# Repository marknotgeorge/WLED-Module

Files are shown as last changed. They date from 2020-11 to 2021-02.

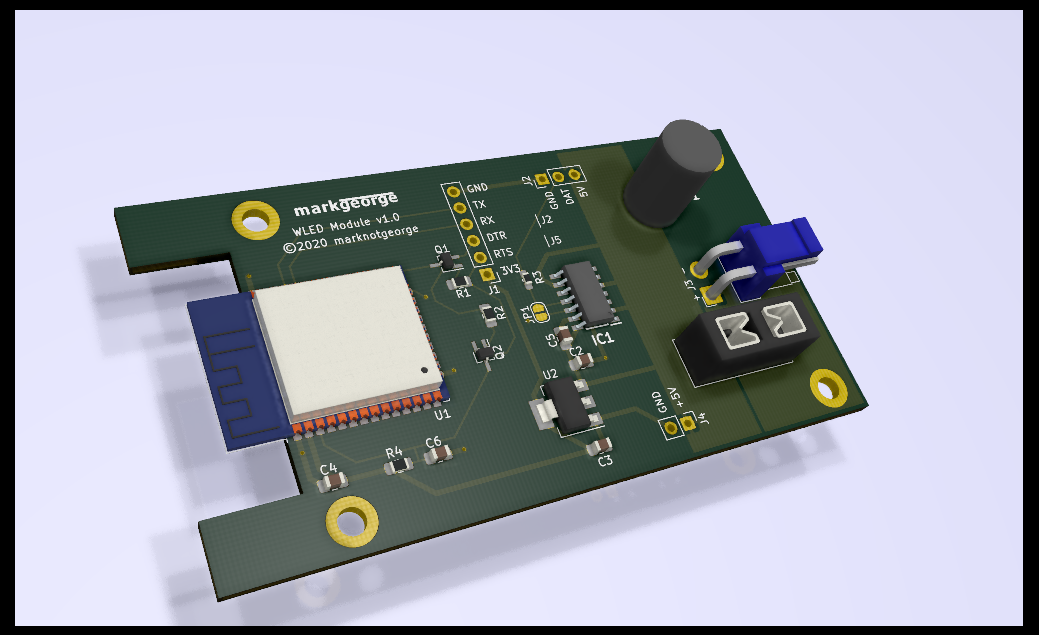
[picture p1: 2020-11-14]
WLED Module.png

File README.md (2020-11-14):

# WLED-Module
A minimal ESP32-based module for controlling a strip of WS2812 (Neopixel) LEDs using WLED

## Features
- Just the components needed. Nothing more, nothing less.
- Programming header for use with a USB-UART dongle, with auto-reset circuitry for buttonless programming.
- Powered from a 5V power brick.

## To Do
- Add extra connector block to help power long strips.
- Add strapping resistor to EN pin.
- Add JLCPCB component codes to facilitate assembly.
- Layout PCB.
- Build it!

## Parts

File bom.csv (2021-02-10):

Comment | Designator | Footprint | LCSC
EEU-FR0J102 | C1 | SamacSys:CAPPRD350W65D800H1300
22uF | C2 | Capacitor_SMD:C_0805_2012Metric_Pad1.15x1.40mm_HandSolder | C45783
22uf | C3 | Capacitor_SMD:C_0805_2012Metric_Pad1.15x1.40mm_HandSolder | C45783
0.1uF | C4,C5 | Capacitor_SMD:C_0805_2012Metric_Pad1.15x1.40mm_HandSolder | C49678
0.1uF 50V | C6 | Capacitor_SMD:C_0805_2012Metric_Pad1.15x1.40mm_HandSolder | C49678
10A | F1 | Fuse:Fuseholder_Blade_Mini_Keystone_3568
MountingHole_Pad | H1,H2,H3,H4 | MountingHole:MountingHole_3.2mm_M3_DIN965_Pad
SN74AHCT125D | IC1 | SamacSys:SOIC127P600X175-14N | C155176
Conn_02x03_Odd_Even | J1 | Connector_IDC:IDC-Header_2x03_P2.54mm_Vertical
JST SM Connector | J2 | Connector_PinHeader_2.54mm:PinHeader_1x03_P2.54mm_Vertical
Conn_01x02_Male | J3 | Connector_JST:JST_VH_B2PS-VH_1x02_P3.96mm_Horizontal
Conn_01x02_Male | J4 | Connector_PinHeader_2.54mm:PinHeader_1x02_P2.54mm_Vertical
SolderJumper_2_Open | JP1 | Jumper:SolderJumper-2_P1.3mm_Open_RoundedPad1.0x1.5mm
470R | R3 | Resistor_SMD:R_0603_1608Metric_Pad1.05x0.95mm_HandSolder | C17710
10K | R4 | Resistor_SMD:R_0805_2012Metric_Pad1.15x1.40mm_HandSolder | C17414
ESP32-WROOM-32D | U1 | RF_Module:ESP32-WROOM-32 | C473012
AMS1117-3.3 | U2 | Package_TO_SOT_SMD:SOT-223-3_TabPin2 | C6186

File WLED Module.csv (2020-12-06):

Id | Designator | Package | Quantity | Designation | Supplier and ref
1 | G*** | marknotgeorge logo | 1 | LOGO
2 | H4,H3,H2,H1 | MountingHole_3.2mm_M3_DIN965_Pad | 4 | MountingHole_Pad
3 | J3 | JST_VH_B2PS-VH_1x02_P3.96mm_Horizontal | 1 | Conn_01x02_Male
4 | F1 | Fuseholder_Blade_Mini_Keystone_3568 | 1 | 10A
5 | J2 | PinHeader_1x03_P2.54mm_Vertical | 1 | JST SM Connector
6 | R1,R2 | R_0805_2012Metric_Pad1.15x1.40mm_HandSolder | 2 | 10k
7 | Q1,Q2 | SOT-323_SC-70_Handsoldering | 2 | SS8050
8 | IC1 | SOIC127P600X175-14N | 1 | SN74AHCT125D
9 | C5,C4 | C_0805_2012Metric_Pad1.15x1.40mm_HandSolder | 2 | 0.1uF
10 | C1 | CAPPRD350W65D800H1300 | 1 | EEU-FR0J102
11 | C2 | C_0805_2012Metric_Pad1.15x1.40mm_HandSolder | 1 | 22uF
12 | C3 | C_0805_2012Metric_Pad1.15x1.40mm_HandSolder | 1 | 22uf
13 | C6 | C_0805_2012Metric_Pad1.15x1.40mm_HandSolder | 1 | 0.1uF 50V
14 | J1 | PinHeader_1x06_P2.54mm_Vertical | 1 | Conn_01x06_Male
15 | JP1 | SolderJumper-2_P1.3mm_Open_RoundedPad1.0x1.5mm | 1 | SolderJumper_2_Open
16 | R3 | R_0603_1608Metric_Pad1.05x0.95mm_HandSolder | 1 | 470R
17 | R4 | R_0805_2012Metric_Pad1.15x1.40mm_HandSolder | 1 | 10K
18 | U1 | ESP32-WROOM-32 | 1 | ESP32-WROOM-32D
19 | U2 | SOT-223-3_TabPin2 | 1 | AMS1117-3.3
20 | J4 | PinHeader_1x02_P2.54mm_Vertical | 1 | Conn_01x02_Male

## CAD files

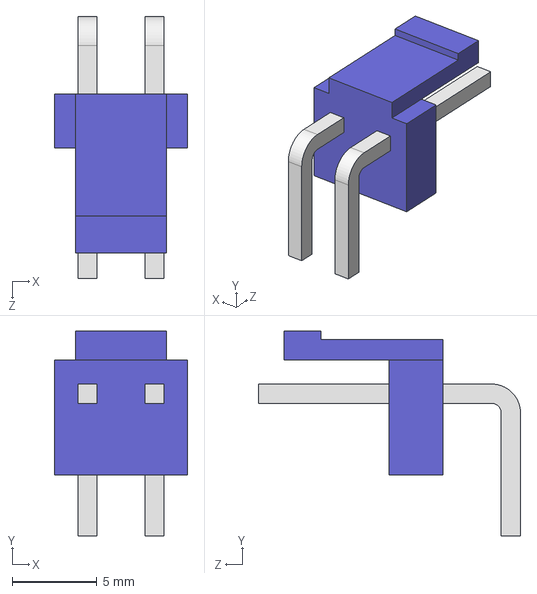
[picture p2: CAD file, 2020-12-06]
B2PS-VH.STEP
7.86 x 12.1 x 15.5 mm

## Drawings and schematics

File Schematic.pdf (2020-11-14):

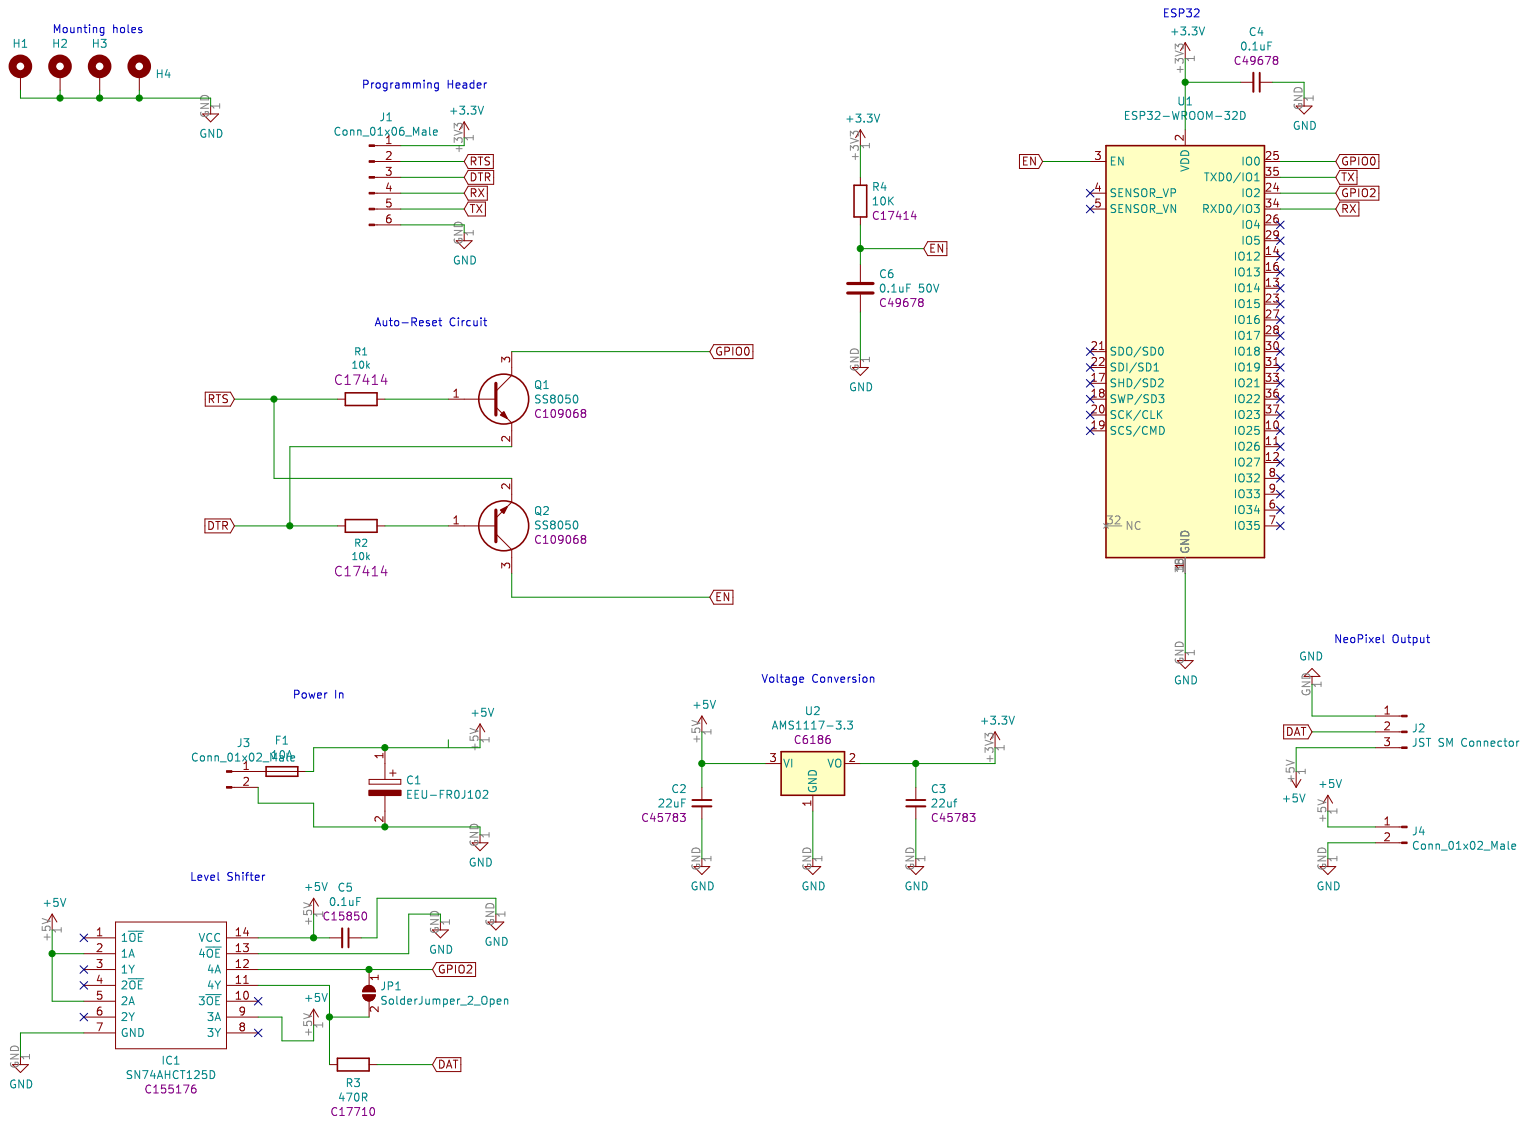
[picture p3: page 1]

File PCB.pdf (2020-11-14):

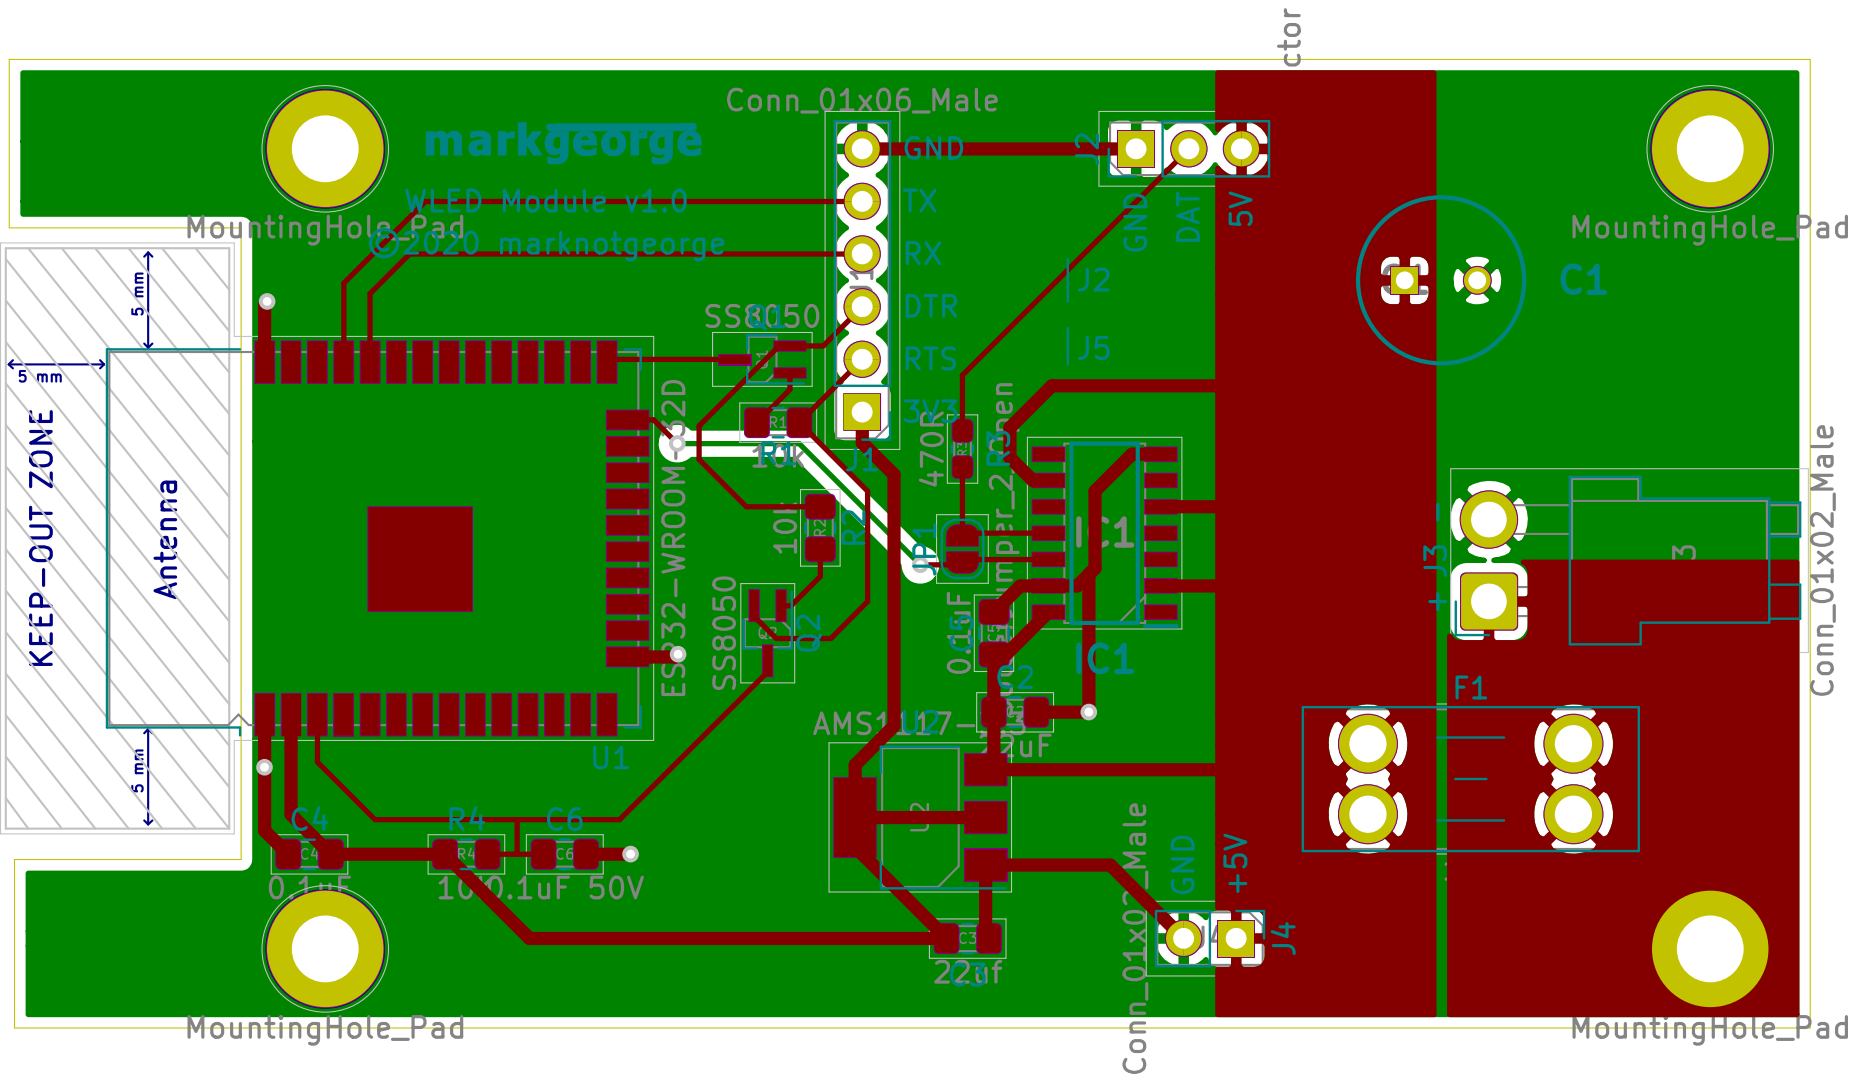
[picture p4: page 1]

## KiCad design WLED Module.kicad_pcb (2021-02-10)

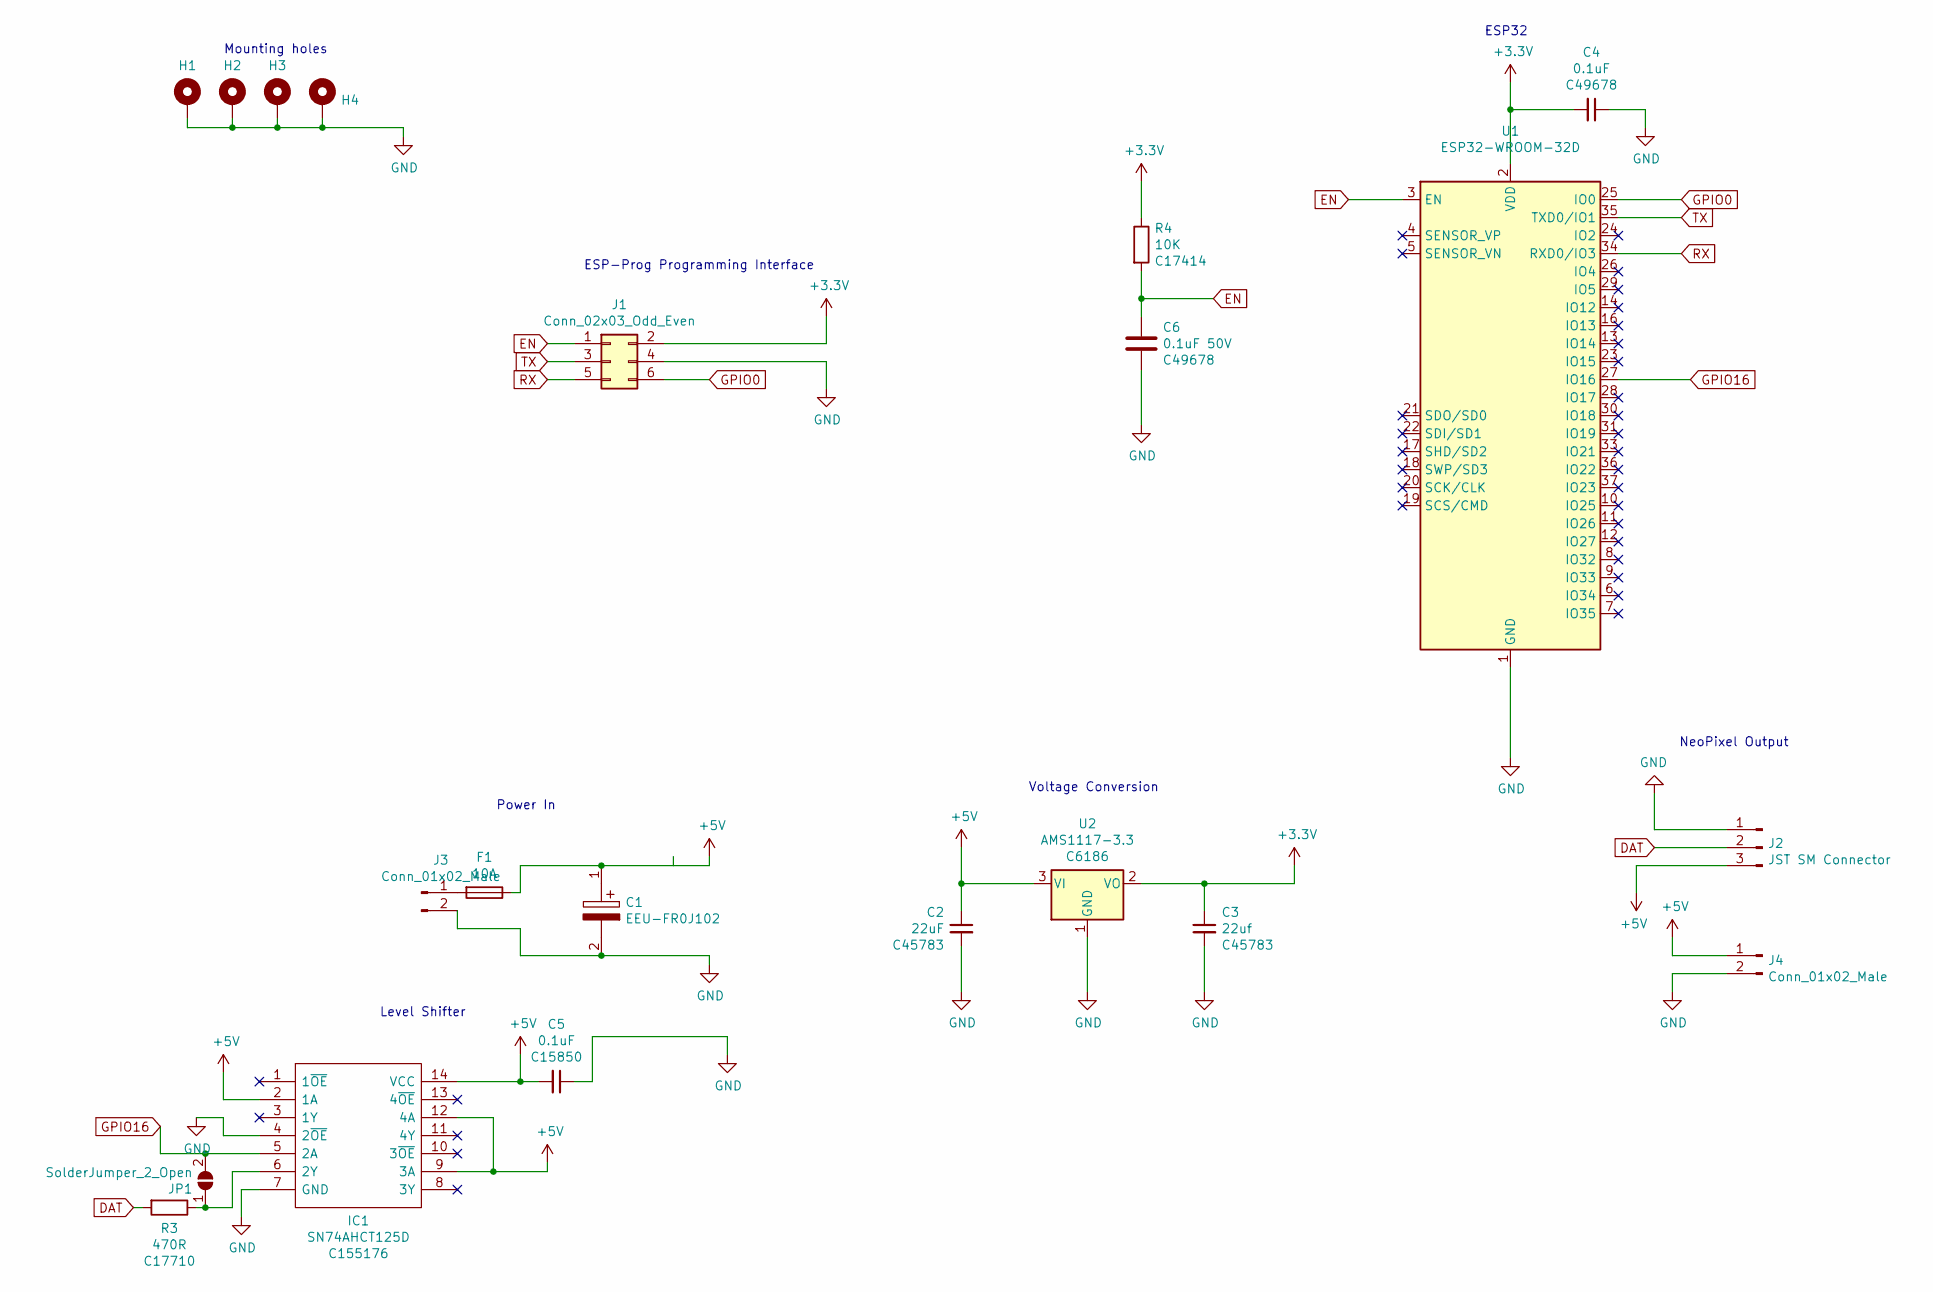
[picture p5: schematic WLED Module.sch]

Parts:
C1: EEU-FR0J102; CAPPRD350W65D800H1300; Manufacturer_Part_Number EEU-FR0J102; Mouser Part Number 667-EEU-FR0J102
C2: 22uF; C_0805_2012Metric_Pad1.15x1.40mm_HandSolder; LCSC C45783
C3: 22uf; C_0805_2012Metric_Pad1.15x1.40mm_HandSolder; LCSC C45783
C4: 0.1uF; C_0805_2012Metric_Pad1.15x1.40mm_HandSolder; LCSC C49678
C5: 0.1uF; C_0805_2012Metric_Pad1.15x1.40mm_HandSolder; LCSC C15850
C6: 0.1uF 50V; C_0805_2012Metric_Pad1.15x1.40mm_HandSolder; LCSC C49678
F1: 10A; Fuseholder_Blade_Mini_Keystone_3568
H1, H2, H3, H4: MountingHole_Pad; MountingHole_3.2mm_M3_DIN965_Pad
IC1: SN74AHCT125D; SOIC127P600X175-14N; Manufacturer_Part_Number SN74AHCT125D; Mouser Part Number 595-SN74AHCT125D
J1: Conn_02x03_Odd_Even; IDC-Header_2x03_P2.54mm_Vertical
J2: JST SM Connector; PinHeader_1x03_P2.54mm_Vertical
J3: Conn_01x02_Male; JST_VH_B2PS-VH_1x02_P3.96mm_Horizontal
J4: Conn_01x02_Male; PinHeader_1x02_P2.54mm_Vertical
JP1: SolderJumper_2_Open; SolderJumper-2_P1.3mm_Open_RoundedPad1.0x1.5mm
R3: 470R; R_0603_1608Metric_Pad1.05x0.95mm_HandSolder; LCSC C17710
R4: 10K; R_0805_2012Metric_Pad1.15x1.40mm_HandSolder; LCSC C17414
U1: ESP32-WROOM-32D; ESP32-WROOM-32
U2: AMS1117-3.3; SOT-223-3_TabPin2; LCSC C6186

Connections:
+3V3: C3.1, C4.2, J1.2, R4.1, U1.2 (VDD), U2.2 (VO)
+5V: C1.1, C2.1, C5.2, F1.1, IC1.2 (1A), IC1.9 (3A), IC1.12 (4A), IC1.14 (VCC), J2.3, J4.1, U2.3 (VI)
DAT: J2.2, R3.2
EN: C6.1, J1.1, R4.2, U1.3 (EN)
GND: C1.2, C2.2, C3.2, C4.1, C5.1, C6.2, H1.1, H2.1, H3.1, H4.1, IC1.4 (2~OE), IC1.7 (GND), J1.4, J2.1, J3.2, J4.2, U1.1 (GND), U1.15 (GND), U1.38 (GND), U1.39 (GND), U2.1 (GND)
GPIO0: J1.6, U1.25 (IO0)
GPIO16: IC1.5 (2A), JP1.2 (B), U1.27 (IO16)
unnamed: F1.2, J3.1
unnamed: IC1.6 (2Y), JP1.1 (A), R3.1
RX: J1.5, U1.34 (RXD0/IO3)
TX: J1.3, U1.35 (TXD0/IO1)

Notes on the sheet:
Power In
Level Shifter
Voltage Conversion
NeoPixel Output
ESP32
Mounting holes
ESP-Prog Programming Interface

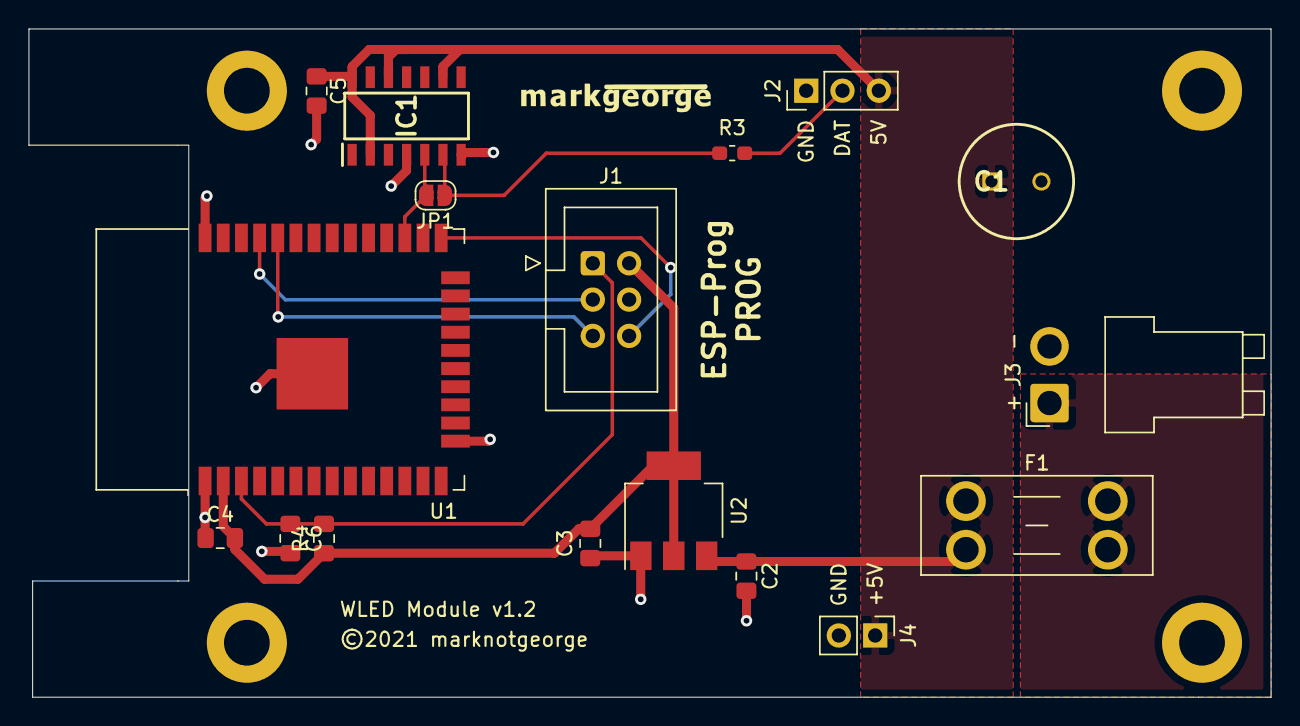
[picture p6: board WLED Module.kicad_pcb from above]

Board: 2 copper layers, 86.9 x 46.7 mm, 21 parts (0 on the bottom side), 11 nets.

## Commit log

2020-11-04 Initial commit (again)
    [WLED Module.kicad_pcb, WLED Module.sch]
2020-11-14 Various revisions:
    Input lines on IC1 tied to VCC.
    Input power connector changed to JST VH type.
    Decoupling capacitors changed to 0.1uf.
    Initial Gerber & other fab files generated.
    [WLED Module-B_Cu.gbr, WLED Module-B_Mask.gbr, WLED Module-B_SilkS.gbr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]
2020-12-06 10A fuse added.
    BOM & Position file for JLCPCB added.
    [B2PS-VH.STEP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]
2021-02-10 V1.2
    * Auto-save circuitry replaced in favour of ESP-Prog interface.
    * Ancillary components rearranged.
    [WLED Module.sch]
2021-02-10 Add the rest of the files. Duh.
    [WLED Module-B_Cu.gbr, WLED Module-B_Mask.gbr, WLED Module-B_SilkS.gbr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]
2021-02-10 Adjustments for JLCPCB assembly.
    [WLED Module.sch, bom.csv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]

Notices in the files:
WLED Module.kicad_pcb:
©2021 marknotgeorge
